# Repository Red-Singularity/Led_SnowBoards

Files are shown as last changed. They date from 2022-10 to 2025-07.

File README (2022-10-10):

The goal of this repository is to share code between all members who have custom LED snowbnoards to expedite the process of getting to the slopes
with actually functioning snowboards

This will not only include the code used on the boards but also possible testbeds, images, and other related files
This will be compartmentalized between users as all boards are built differently and require different code
this will allow merges to go a lot smoother since ideally only the user who created the code commited here will be modifying it
This also allows other people to view and test other members code though

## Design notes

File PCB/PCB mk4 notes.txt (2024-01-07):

* silk screen for labeling not showing
* level shifter needs to be the TXS0104EDR
* power switch needs pull down resistor
* op amp needs 12v power. only on when power switch is hit
* make connectors different for led data lines
* make sure fuse blows when crowbar circuit is active
* change diodes / thyristor circuit to actually work
* ground clamp test point (looping test point)
* bat test point messed up
* make components assemblable by jlcpcb
* better pin 1 markings
* bottom pad on mpu6050 doesnt exist
* add 10k pull up resistors to encoder data pins

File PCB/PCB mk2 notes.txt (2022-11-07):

keep dual xt-60
move connectors

have single xt-60 power output
use jst for signal output/input

less wide pcb

appropriately sized mosfets

fuse stupid size. keep soldered in

add rotary encoder / potentiometer

add i2c line 

fix foot print for gps

gyro fix footprint

mpu fix footprint

add current shunt if it doesnt affect size

make led dimmer, amount of status leds is good at 2

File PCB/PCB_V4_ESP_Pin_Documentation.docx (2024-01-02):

Left (EN button) Side Pins:

1. RESET
  a. GPIO: N/A
  b. Purpose: Resets the ESP32 and GPS module
  c. Connections:
    i. Reset test point
    ii. Reset pin (pin 8) of GPS module (NEO-M8M)
  d. Libraries: N/A
2. CELL1
  a. GPIO: 36
  b. Purpose: Analog input for cell 1 battery voltage from op-amp circuit
  c. Connections:
    i. CELL1 test point
    ii. CELL1 pin (pin 1) of op-amp (LM124DR)
  d. Libraries: N/A
3. CELL2
  a. GPIO: 39
  b. Purpose: Analog input for cell 2 battery voltage from op-amp circuit
  c. Connections:
    i. CELL2 test point
    ii. CELL2 pin (pin 7) of op-amp (LM124DR)
  d. Libraries: N/A
4. CELL3
  a. GPIO: 34
  b. Purpose: Analog input for cell 3 battery voltage from op-amp circuit
  c. Connections:
    i. CELL3 test point
    ii. CELL3 pin (pin 8) of op-amp (LM124DR)
  d. Libraries: N/A
5. SENSOR
  a. GPIO: 35
  b. Purpose: Analog input for 3-pin sensor (i.e. potentiometer or pressure-variable resistor)
  c. Connections:
    i. SENSOR test point
    ii. SENSOR pin (pin 1) of J8 connector (JST-XA type)
  d. Libraries: N/A
6. GATE_SIGNAL
  a. GPIO: 32
  b. Purpose: Digital output to control 12V power supply to the LEDs
  c. Connections:
    i. GATE_SIGNAL test point
    ii. Gate pin (pin 2) of Q1 MOSFET through R16
    iii. Gate pin (pin 2) of Q2 MOSFET through R17
    iv. GATE_SIGNAL pin (pin 8) of level shifter (TXS0104ED)
  d. Libraries: N/A
7. SW
  a. GPIO: 33
  b. Purpose: Digital input for the button switch on rotary encoder
    i. Note: We assume a normally HIGH switch (3.3V through R18). For a normally LOW switch, remove R18
  c. Connections:
    i. SW test point
    ii. SW pin (pin 3) of J9 connector (JST-XA type) for 5-pin rotary encoder
  d. Libraries: N/A
8. DT
  a. GPIO: 25
  b. Purpose: Digital input for circuit “A” of biphase rotary encoder
  c. Connections:
    i. DT test point
    ii. DT pin (pin 2) of J9 connector (JST-XA type) for 5-pin rotary encoder
  d. Libraries: <Encoder.h>
9. CLK
  a. GPIO: 26
  b. Purpose: Digital input for circuit “B” of biphase rotary encoder
  c. Connections:
    i. CLK test point
    ii. CLK pin (pin 1) of J9 connector (JST-XA type) for 5-pin rotary encoder
  d. Libraries: <Encoder.h>
10. SD_SW
  a. GPIO: 27
  b. Purpose: Digital input for detecting an SD card in the card socket
  c. Connections:
    i. SD_SW test point
    ii. SD_SW pin (pin 10) of micro-SD card socket (DM3AT-SF-PEJM5)
  d. Libraries: N/A
11. DATA_3
  a. GPIO: 14
  b. Purpose: Digital output for LED data on the 3rd data wire
  c. Connections:
    i. DATA_3 test point
    ii. DATA_3 pin (pin 4) of the level shifter (TXS0104ED)
      1. Signal output from the level shifter (pin 11) at 5V to pin 3 of J7 connector (JST-XA type)
  d. Libraries: <Adafruit_NeoPixel.h>
12. DATA_1
  a. GPIO: 12
  b. Purpose: Digital output for LED data on the 1st data wire
  c. Connections:
    i. DATA_1 test point
    ii. DATA_1 pin (pin 2) of the level shifter (TXS0104ED)
      1. Signal output from the level shifter (pin 13) at 5V to pin 1 of J7 connector (JST-XA type)
  d. Libraries: <Adafruit_NeoPixel.h>
13. DATA_2
  a. GPIO: 13
  b. Purpose: Digital output for LED data on the 2nd data wire
  c. Connections:
    i. DATA_2 test point
    ii. DATA_2 pin (pin 3) of the level shifter (TXS0104ED)
      1. Signal output from the level shifter (pin 12) at 5V to pin 2 of J7 connector (JST-XA type)
  d. Libraries: <Adafruit_NeoPixel.h>
14. GND
  a. GPIO: N/A
  b. Purpose: Ground pin of ESP32
  c. Connections: GND of PCB
  d. Libraries: N/A
15. x
  a. GPIO: N/A
  b. Purpose: VIN pin of ESP32 (not used here, as we supply 3.3V directly)
  c. Connections: N/A
  d. Libraries: N/A

Right (BOOT button) Side Pins:

16. MOSI
  a. GPIO: 23
  b. Purpose: VSPI serial output (from ESP32 to RAM and SD card)
  c. Connections:
    i. MOSI pin (pin 5) of RAM (Adafruit 4677)
    ii. MOSI test point
    iii. MOSI pin (pin 3) of micro-SD card socket (DM3AT-SF-PEJM5)
  d. Libraries:
    i. RAM: Needed
    ii. SD card: Needed
17. SCL
  a. GPIO: 22
  b. Purpose: I²C serial clock
  c. Connections:
    i. SCL pin (pin 5) of power monitor (INA220BIDGSR)
    ii. SCL test point
    iii. SCL pin (pin 23) of IMU (MPU-6050)
  d. Libraries:
    i. Power monitor: Needed
    ii. IMU: Needed
18. x
  a. GPIO: 1
  b. Purpose: not used, UART 0 TX
  c. Connections: N/A
  d. Libraries: N/A
19. x
  a. GPIO: 3
  b. Purpose: not used, UART 0 RX
  c. Connections: N/A
  d. Libraries: N/A
20. SDA
  a. GPIO: 21
  b. Purpose: I²C serial data line
  c. Connections:
    i. SDA pin (pin 4) of power monitor (INA220BIDGSR)
    ii. SDA test point
    iii. SDA pin (pin 24) of IMU (MPU-6050)
  d. Libraries:
    i. Power monitor: Needed
    ii. IMU: Needed
21. MISO
  a. GPIO: 19
  b. Purpose: VSPI serial input (from RAM and SD card to ESP32)
  c. Connections:
    i. MISO pin (pin 2) of RAM (Adafruit 4677)
    ii. MISO test point
    iii. MISO pin (pin 7) of micro-SD card socket (DM3AT-SF-PEJM5)
  d. Libraries:
    i. RAM: Needed
    ii. SD card: Needed
22. SCLK
  a. GPIO: 18
  b. Purpose: VSPI serial clock for RAM and SD card
  c. Connections:
    i. SCLK pin (pin 6) of RAM (Adafruit 4677)
    ii. SCLK test point
    iii. SCLK pin (pin 5) of micro-SD card socket (DM3AT-SF-PEJM5)
  d. Libraries:
    i. RAM: Needed
    ii. SD card: Needed
23. CS_SD
  a. GPIO: 5
  b. Purpose: SD card chip selection for VSPI serial communication
  c. Connections:
    i. CS_SD test point
    ii. CS_SD pin (pin 2) of micro-SD card socket (DM3AT-SF-PEJM5)
  d. Libraries: Needed
24. TX
  a. GPIO: 17
  b. Purpose: UART output (from ESP32 to GPS)
  c. Connections:
    i. TX test point
    ii. TX pin (pin 21) of GPS module (NEO-M8M-0)
  d. Libraries: <TinyGPS++.h> & <SoftwareSerial.h>
25. RX
  a. GPIO: 16
  b. Purpose: UART input (from GPS to ESP32)
  c. Connections:
    i. RX test point
    ii. RX pin (pin 20) of GPS module (NEO-M8M-0)
  d. Libraries: <TinyGPS++.h> & <SoftwareSerial.h>
26. INT
  a. GPIO: 4
  b. Purpose: Digital interrupt input (from IMU to ESP32)
    i. The MPU-6050 can be configured to give an interrupt signal for:
      1. Clock generator switching oscillator frequency
      2. New data available
      3. Accelerometer events
      4. Secondary I²C bus communication failure
  c. Connections:
    i. INT test point
    ii. INT pin (pin 12) of IMU (MPU-6050)
  d. Libraries: N/A
27. CS_RAM
  a. GPIO: 2
  b. Purpose: RAM chip selection for VSPI serial communication
  c. Connections:
    i. CS_RAM test point
    ii. CS_RAM pin (pin 1) of RAM (Adafruit 4677)
  d. Libraries: Needed
28. x
  a. GPIO: 15
  b. Purpose: Not used
  c. Connections: N/A
  d. Libraries: N/A
29. GND
  a. GPIO: N/A
  b. Purpose: Ground pin of ESP32
  c. Connections: GND of PCB
  d. Libraries: N/A
30. +3V3
  a. GPIO: N/A
  b. Purpose: 3.3V input of ESP32
  c. Connections: 3.3V rail of PCB
  d. Libraries: N/A

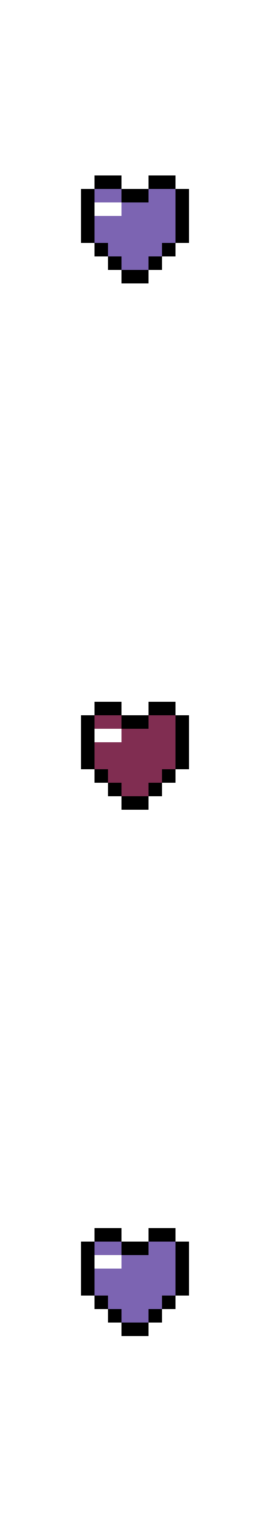
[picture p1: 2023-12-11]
_Dustin/media/The_Heart_of_Neon_board.gif

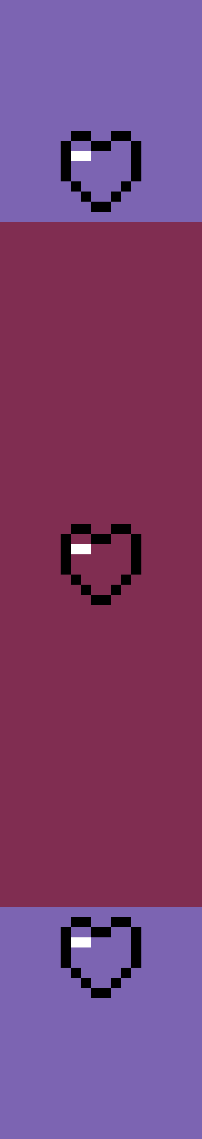
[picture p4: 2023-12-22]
_Dustin/media/The_Heart_of_Neon_board_background.gif

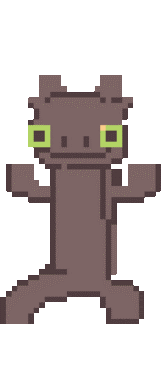
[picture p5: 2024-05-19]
_Dustin/media/toothless.gif

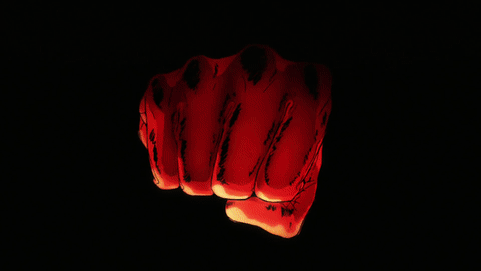
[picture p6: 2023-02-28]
_Dustin/media/onepunch.gif

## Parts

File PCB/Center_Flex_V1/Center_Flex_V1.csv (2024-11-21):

# | Reference | Qty | Value | Footprint | DNP
1 | FID1, FID2, FID3, FID4, FID5, FID6, FID7, FID8, FID9 | 9 | Fiducial | Fiducial:Fiducial_1.5mm_Mask3mm
2 | H1, H2, H3, H4, H5, H6, H7, H8 | 8 | MountingHole | Dustins_Footprints:4mm Solder Pad
3 | J1, J5, J9, J11, J15, J19, J24, J28, J34, J38, J117, J119 | 12 | Conn_01x02_Pin | Dustins_Footprints:Snowboard_Flex_Solder_Pad
4 | J2, J6, J10, J12, J16, J20, J23, J27, J33, J37, J118, J120 | 12 | Conn_01x02_Socket | Dustins_Footprints:Snowboard_Flex_Solder_pad_short
5 | J3, J7, J13, J17, J22, J26, J30, J32, J36, J40, J114, J116 | 12 | Conn_01x02_Socket | Dustins_Footprints:Snowboard_Flex_Solder_Pad
6 | J4, J8, J14, J18, J21, J25, J29, J31, J35, J39, J113, J115 | 12 | Conn_01x02_Pin | Dustins_Footprints:Snowboard_Flex_Solder_pad_short
7 | J41, J43, J44, J46 | 4 | Conn_01x01_Pin | Dustins_Footprints:5mm THT Circular
8 | J42, J45 | 2 | Conn_01x02_Socket | Dustins_Footprints:SnowBoard Flex Pass Through Pads Short
9 | J47, J50, J52, J54, J56, J58, J60, J62, J64, J66, J68, J70, J72, J74, J76, J78, J80, J81 | 18 | Conn_01x01_Socket | Dustins_Footprints:5mm THT Circular
10 | J48, J49, J51, J53, J55, J57, J59, J61, J63, J65, J67, J69, J71, J73, J75, J77, J79, J82 | 18 | Conn_01x01_Socket | Dustins_Footprints:5mm THT Square
11 | J83, J84, J85, J86, J87, J88, J89, J90, J98, J99, J100, J101, J102, J103, J104 | 15 | Conn_01x01_Pin | Dustins_Footprints:SnowBoard Power Pads
12 | J91, J92, J93, J94, J95, J96, J97, J105, J106, J107, J108, J109, J110, J111, J112 | 15 | Conn_01x01_Pin | Dustins_Footprints:SnowBoard Power Pads Short
13 | U1, U2, U3, U4, U5, U6, U7, U8, U9, U10, U11, U12, U13, U14, U15, U16, U17, U18, U19, U20, U21, U22, U23, U24, U25, U26, U27, U28, U29, U30, U31, U32, U33, U34, U35, U36, U37, U38, U39, U40, U41, U42, U43, U44, U45, U46, U47, U48, U49, U50, U51, U52, U53, U54, U55, U56, U57, U58, U59, U60, U61, U62, U63, U64, U65, U66, U67, U68, U69, U70, U71, U72, U73, U74, U75, U76, U77, U78, U79, U80, U81, U82, U83, U84, U85, U86, U87, U88, U89, U90, U91, U92, U93, U94, U95, U96, U97, U98, U99, U100, U101, U102, U103, U104, U105, U106, U107, U108, U109, U110, U111, U112, U113, U114, U115, U116, U117, U118, U119, U120, U121, U122, U123, U124, U125, U126, U127, U128, U129, U130, U131, U132, U133, U134, U135, U136, U137, U138, U139, U140, U141, U142, U143, U144, U145, U146, U147, U148, U149, U150, U151, U152, U153, U154, U155, U156, U157, U158, U159, U160, U161, U162, U163, U164, U165, U166, U167, U168, U169, U170, U171, U172, U173, U174, U175, U176, U177, U178, U179, U180, U181, U182, U183, U184, U185, U186, U187, U188, U189, U190, U191, U192, U193, U194, U195, U196, U197, U198, U199, U200, U201, U202, U203, U204, U205, U206, U207, U208, U209, U210, U211, U212, U213, U214, U215, U216, U217, U218, U219, U220, U221, U222, U223, U224, U225, U226, U227, U228, U229, U230, U231, U232, U233, U234, U235, U236, U237, U238, U239, U240, U241, U242, U243, U244, U245, U246, U247, U248, U249, U250, U251, U252, U253, U254, U255, U256, U257, U258, U259, U260, U261, U262, U263, U264, U265, U266, U267, U268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 | 840 | ~ | Dustins_Footprints:WS2816-2121

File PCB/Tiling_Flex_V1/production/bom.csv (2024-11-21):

Designator | Footprint | Quantity | Value | LCSC Part #
FID1, FID2, FID3, FID4, FID5, FID6, FID7, FID8, FID9 | Fiducial_1.5mm_Mask3mm | 9 | Fiducial
J1, J10, J11, J12, J13, J14, J15, J2, J3, J4, J5, J6, J7, J8, J9 | SnowBoard Power Pads | 15 | Conn_01x01_Pin
J100, J101, J102, J103, J104, J105, J106, J107, J108, J109, J110, J111, J112, J113, J114, J115, J116, J117, J118, J119, J120, J121, J122, J123, J124, J125, J126, J127, J128, J129, J130, J131, J132, J133, J134, J135, J136, J137, J138, J139, J140, J141, J142, J143, J144, J145, J146, J147, J148, J149, J150, J151, J152, J153, J154, J155, J156, J157, J158, J159, J160, J161, J162, J211, J212, J213, J214, J215, J216, J217, J218, J219, J220, J221, J222, J223, J224, J225, J226, J227, J228, J229, J230, J231, J232, J233, J234, J235, J236, J237, J238, J239, J240, J241, J242, J243, J244, J245, J246, J247, J248, J249, J250, J251, J252, J253, J254, J255, J256, J257, J258, J259, J260, J261, J262, J263, J264, J265, J266, J267, J268, J269, J270, J271, J272, J273, J274, J47, J48, J75, J76, J87, J88, J89, J90, J91, J92, J93, J94, J95, J96, J97, J98, J99 | Test Pad | 144 | Conn_01x01_Pin
J16, J17, J18, J19, J20, J21, J22, J23, J24, J25, J26, J27, J28, J29, J30 | SnowBoard Power Pads Short | 15 | Conn_01x01_Pin
J31, J37, J41, J45, J52, J56, J59, J65, J69, J73, J80, J84 | Snowboard_Flex_Solder_pad_short | 12 | Conn_01x02_Pin
J32, J38, J42, J46, J51, J55, J60, J66, J70, J74, J79, J83 | Snowboard_Flex_Solder_Pad | 12 | Conn_01x02_Socket
J33, J61 | SnowBoard Flex Pass Through Pads | 2 | Conn_01x02_Socket
J34, J62 | SnowBoard Flex Pass Through Pads Short | 2 | Conn_01x02_Pin
J35, J39, J43, J50, J54, J58, J63, J67, J71, J78, J82, J86 | Snowboard_Flex_Solder_pad_short | 12 | Conn_01x02_Socket
J36, J40, J44, J49, J53, J57, J64, J68, J72, J77, J81, J85 | Snowboard_Flex_Solder_Pad | 12 | Conn_01x02_Pin
JP1, JP10, JP11, JP12, JP13, JP14, JP15, JP16, JP17, JP18, JP19, JP2, JP20, JP21, JP22, JP23, JP24, JP25, JP26, JP27, JP28, JP29, JP3, JP30, JP31, JP32, JP33, JP34, JP35, JP36, JP37, JP38, JP39, JP4, JP40, JP41, JP42, JP43, JP44, JP5, JP6, JP7, JP8, JP9 | SolderJumper-2_P1.3mm_Open_RoundedPad1.0x1.5mm | 44 | SolderJumper_2_Open
U1, U10, U100, U106, U107, U108, U109, U11, U110, U111, U112, U113, U114, U115, U116, U117, U118, U119, U12, U120, U121, U122, U123, U124, U125, U126, U127, U128, U129, U13, U130, U14, U15, U16, U17, U18, U19, U2, U20, U21, U22, U23, U24, U25, U26, U27, U28, U29, U3, U30, U31, U32, U33, U34, U35, U4, U41, U42, U43, U44, U45, U46, U47, U48, U49, U5, U50, U51, U52, U53, U54, U55, U56, U57, U58, U59, U6, U60, U61, U62, U63, U64, U65, U66, U67, U68, U69, U7, U70, U71, U72, U73, U74, U75, U76, U77, U78, U79, U8, U80, U81, U82, U83, U84, U85, U86, U87, U88, U89, U9, U90, U91, U92, U93, U94, U95, U96, U97, U98, U99 | WS2816-2121 | 120 | ~

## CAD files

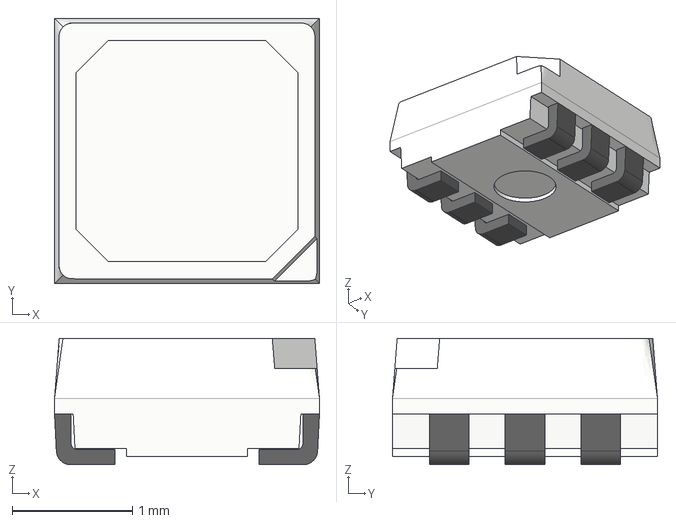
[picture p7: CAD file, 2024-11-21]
PCB/WS2816C-2121.step
2.20 x 2.20 x 1.05 mm

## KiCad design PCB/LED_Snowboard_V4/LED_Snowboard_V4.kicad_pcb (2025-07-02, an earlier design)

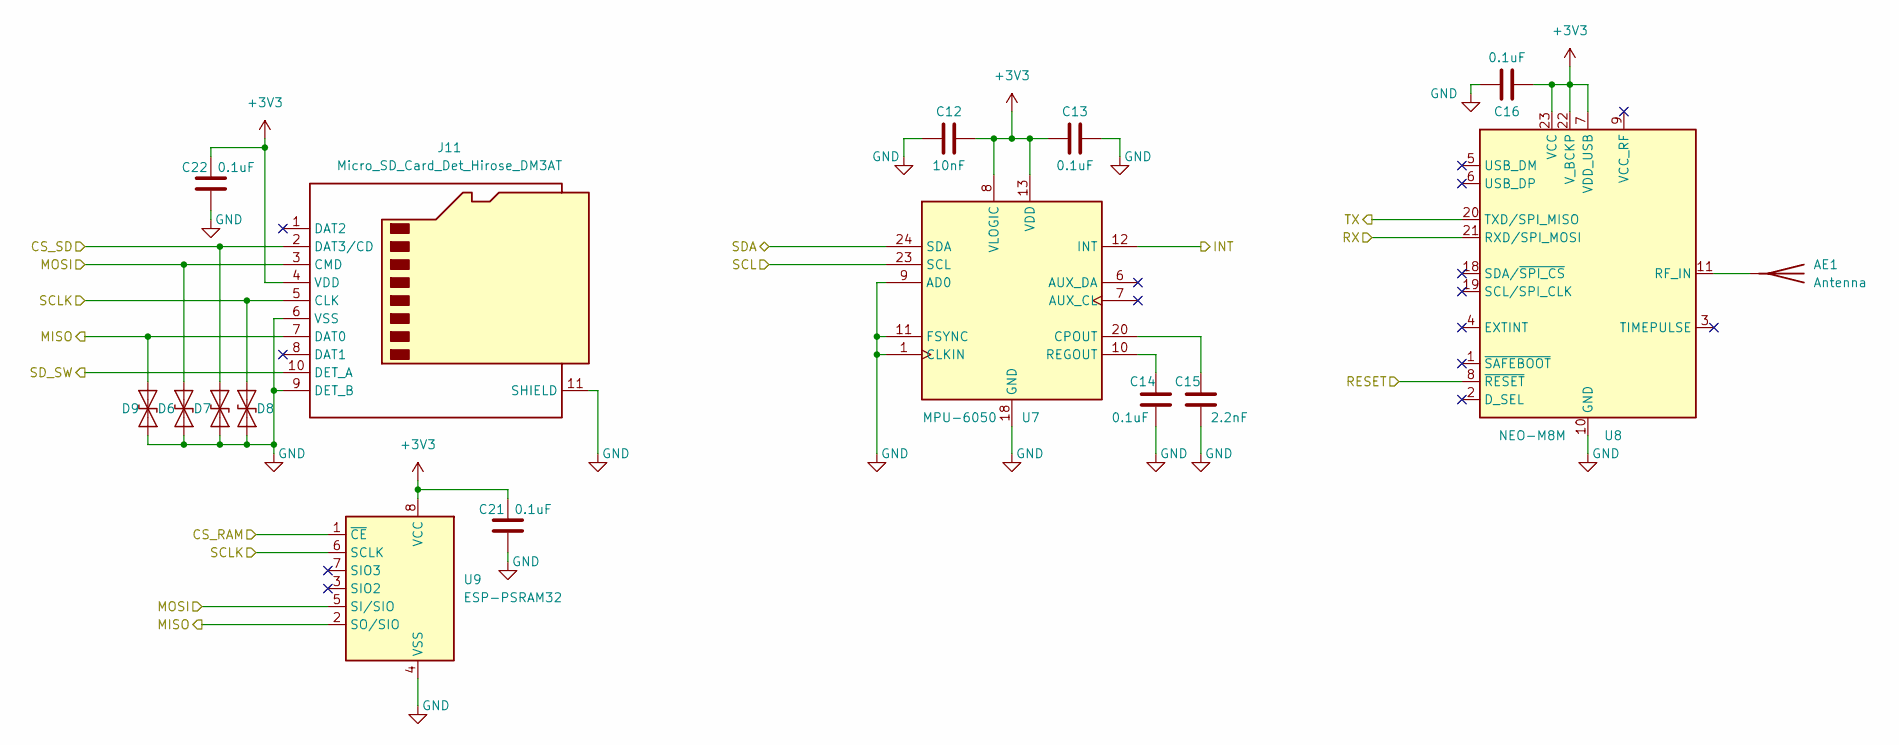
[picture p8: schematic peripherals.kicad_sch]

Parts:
AE1: Antenna; U.FL_Hirose_U.FL-R-SMT-1_Vertical
C12: 10nF; C_0603_1608Metric_Pad1.08x0.95mm_HandSolder
C13, C14, C16, C21, C22: 0.1uF; C_0603_1608Metric_Pad1.08x0.95mm_HandSolder
C15: 2.2nF; C_0603_1608Metric_Pad1.08x0.95mm_HandSolder
D6, D7, D8, D9: SD05_SOD323; D_SOD-323
J11: Micro_SD_Card_Det_Hirose_DM3AT; microSD_HC_Hirose_DM3AT-SF-PEJM5
U7: MPU-6050; InvenSense_QFN-24_4x4mm_P0.5mm
U8: NEO-M8M; ublox_NEO
U9: ESP-PSRAM32; SOIC-8_3.9x4.9mm_P1.27mm

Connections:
+3V3: C12.2, C13.1, C16.1, C21.2, C22.2, J11.4 (VDD), U7.8 (VLOGIC), U7.13 (VDD), U8.7 (VDD_USB), U8.22 (V_BCKP), U8.23 (VCC), U9.8 (VCC); also elsewhere on the board
/IO and Power/SCL: U7.23 (SCL); also elsewhere on the board
/IO and Power/SDA: U7.24 (SDA); also elsewhere on the board
/esp32/CS_RAM: U9.1 (~CE); also elsewhere on the board
/esp32/CS_SD: D7.2 (A2), J11.2 (DAT3/CD); also elsewhere on the board
/esp32/INT: U7.12 (INT); also elsewhere on the board
/esp32/MISO: D9.2 (A2), J11.7 (DAT0), U9.2 (SO/SIO); also elsewhere on the board
/esp32/MOSI: D6.2 (A2), J11.3 (CMD), U9.5 (SI/SIO); also elsewhere on the board
/esp32/RESET: U8.8 (~RESET); also elsewhere on the board
/esp32/RX: U8.20 (TXD/SPI_MISO); also elsewhere on the board
/esp32/SCLK: D8.2 (A2), J11.5 (CLK), U9.6 (SCLK); also elsewhere on the board
/esp32/SD_SW: J11.10 (DET_A); also elsewhere on the board
/esp32/TX: U8.21 (RXD/SPI_MOSI); also elsewhere on the board
GND: C12.1, C13.2, C14.1, C15.1, C16.2, C21.1, C22.1, D6.1 (A1), D7.1 (A1), D8.1 (A1), D9.1 (A1), J11.6 (VSS), J11.9 (DET_B), J11.11 (SHIELD), U7.1 (CLKIN), U7.9 (AD0), U7.11 (FSYNC), U7.18 (GND), U8.10 (GND), U8.12 (GND), U8.13 (GND), U8.24 (GND), U9.4 (VSS); also elsewhere on the board
unnamed: AE1.1 (A), U8.11 (RF_IN)
unnamed: C15.2, U7.20 (CPOUT)
unnamed: C14.2, U7.10 (REGOUT)

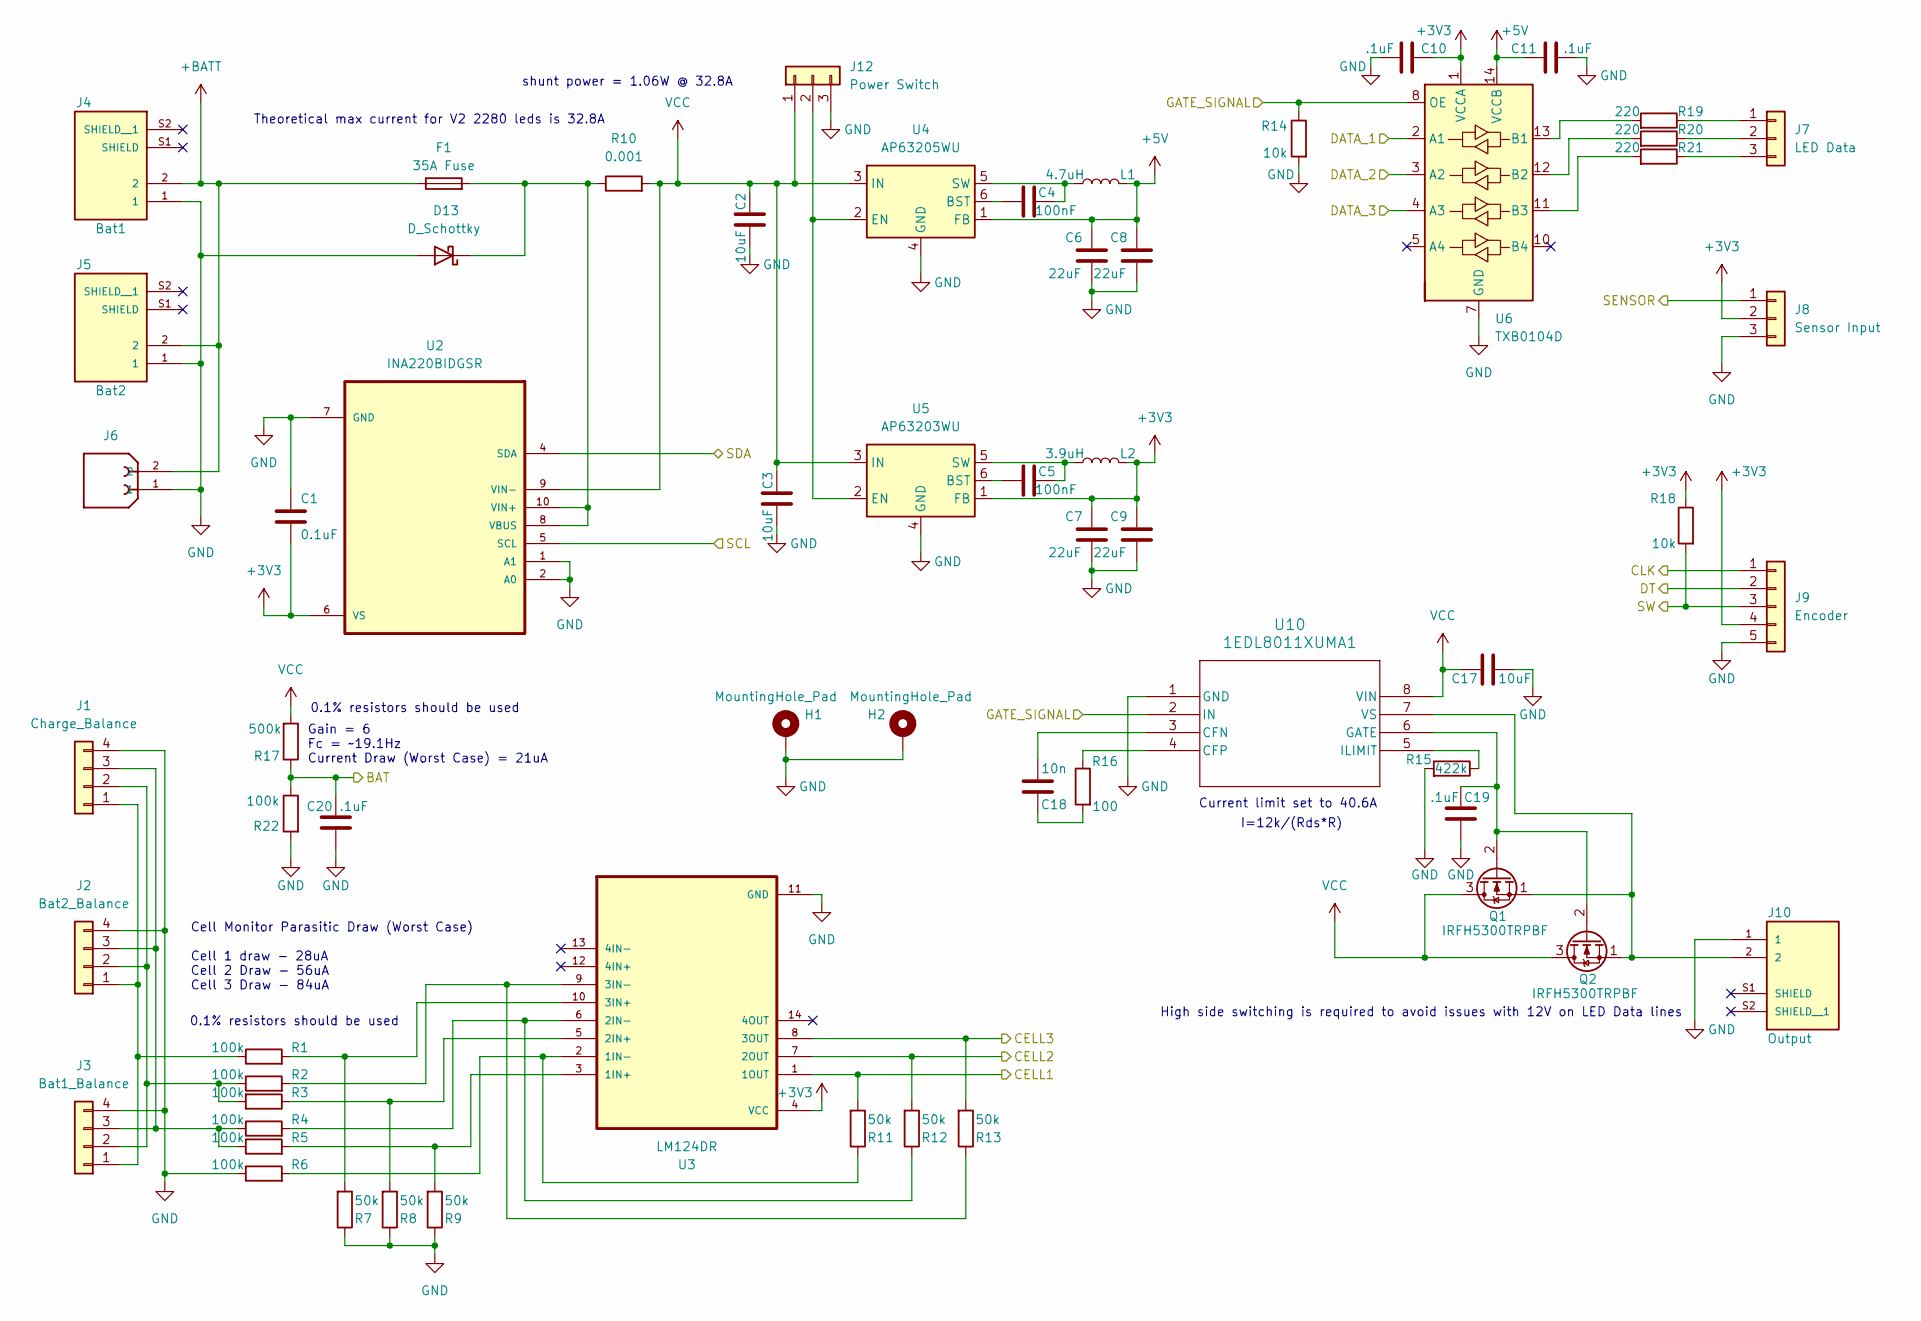
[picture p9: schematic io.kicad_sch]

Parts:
C1: 0.1uF; C_0603_1608Metric_Pad1.08x0.95mm_HandSolder
C2, C3, C17: 10uF; C_0603_1608Metric_Pad1.08x0.95mm_HandSolder
C4, C5: 100nF; C_0603_1608Metric_Pad1.08x0.95mm_HandSolder
C6, C7, C8, C9: 22uF; C_0603_1608Metric_Pad1.08x0.95mm_HandSolder
C10, C11, C19, C20: .1uF; C_0603_1608Metric_Pad1.08x0.95mm_HandSolder
C18: 10n; C_0603_1608Metric_Pad1.08x0.95mm_HandSolder
D13: D_Schottky; TO-263-3_TabPin2
F1: 35A Fuse; SF-3812F3500T-2
H1, H2: MountingHole_Pad; MountingHole_4.3mm_M4_Pad
J1: Charge_Balance; JST_XA_B04B-XASK-1_1x04_P2.50mm_Vertical
J2: Bat2_Balance; JST_XA_S04B-XASK-1N-BN_1x04_P2.50mm_Horizontal
J3: Bat1_Balance; JST_XA_S04B-XASK-1N-BN_1x04_P2.50mm_Horizontal
J4: Bat1; AMASS_XT60PW-M_1x02_P7.20mm_Horizontal; PARTREV V1.2
J5: Bat2; AMASS_XT60PW-M_1x02_P7.20mm_Horizontal; PARTREV V1.2
J6: AMASS_XT30U-M_1x02_P5.0mm_Vertical
J7: LED Data; JST_XA_B03B-XASK-1_1x03_P2.50mm_Vertical
J8: Sensor Input; JST_XA_B03B-XASK-1_1x03_P2.50mm_Vertical
J9: Encoder; JST_XA_B05B-XASK-1_1x05_P2.50mm_Vertical
J10: Output; AMASS_XT60PW-F_1x02_P7.20mm_Horizontal; PARTREV V1.2
J12: Power Switch; Molex_Nano-Fit_105309-xx03_1x03_P2.50mm_Vertical
L1: 4.7uH; IND_SRR4818A-150M
L2: 3.9uH; IND_SRR4818A-150M
Q1, Q2: IRFH5300TRPBF; PQFN-8-EP_6x5mm_P1.27mm_Generic
R1, R2, R3, R4, R5, R6, R22: 100k; R_0603_1608Metric_Pad0.98x0.95mm_HandSolder
R7, R8, R9, R11, R12, R13: 50k; R_0603_1608Metric_Pad0.98x0.95mm_HandSolder
R10: 0.001; RES_WSK12161L000FEA
R14, R18: 10k; R_0603_1608Metric_Pad0.98x0.95mm_HandSolder
R15: 422k; R_0603_1608Metric_Pad0.98x0.95mm_HandSolder
R16: 100; R_0603_1608Metric_Pad0.98x0.95mm_HandSolder
R17: 500k; R_0603_1608Metric_Pad0.98x0.95mm_HandSolder
R19, R20, R21: 220; R_0603_1608Metric_Pad0.98x0.95mm_HandSolder
U2: INA220BIDGSR; SOP50P490X110-10N
U3: LM124DR; SOIC127P600X175-14N
U4: AP63205WU; TSOT-23-6
U5: AP63203WU; TSOT-23-6
U6: TXB0104D; SOIC-14_3.9x8.7mm_P1.27mm
U10: 1EDL8011XUMA1; PG-DSO-8-92_INF

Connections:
+3V3: C1.2, C7.2, C9.2, C10.1, J8.2, J9.4, L2.2, R18.1, U2.6 (VS), U3.4 (VCC), U5.1 (FB), U6.1 (VCCA); also elsewhere on the board
+5V: C6.2, C8.2, C11.1, L1.2, U4.1 (FB), U6.14 (VCCB); also elsewhere on the board
+BATT: F1.1, J4.2, J5.2, J6.2; also elsewhere on the board
/IO and Power/BAT: C20.2, R17.1, R22.1; also elsewhere on the board
/IO and Power/CELL1: R11.2, U3.1 (1OUT); also elsewhere on the board
/IO and Power/CELL2: R12.2, U3.7 (2OUT); also elsewhere on the board
/IO and Power/CELL3: R13.2, U3.8 (3OUT); also elsewhere on the board
/IO and Power/CLK: J9.1; also elsewhere on the board
/IO and Power/DATA_1: U6.2 (A1); also elsewhere on the board
/IO and Power/DATA_2: U6.3 (A2); also elsewhere on the board
/IO and Power/DATA_3: U6.4 (A3); also elsewhere on the board
/IO and Power/DT: J9.2; also elsewhere on the board
/IO and Power/GATE_SIGNAL: R14.1, U6.8 (OE), U10.2 (IN); also elsewhere on the board
/IO and Power/SCL: U2.5 (SCL); also elsewhere on the board
/IO and Power/SDA: U2.4 (SDA); also elsewhere on the board
/IO and Power/SENSOR: J8.1; also elsewhere on the board
/IO and Power/SW: J9.3, R18.2; also elsewhere on the board
GND: C1.1, C2.1, C3.1, C6.1, C7.1, C8.1, C9.1, C10.2, C11.2, C17.1, C19.1, C20.1, D13.3 (A), H1.1, H2.1, J1.4, J2.4, J3.4, J4.1, J5.1, J6.1, J8.3, J9.5, J10.1, J12.3, R6.1, R7.1, R8.1, R9.1, R14.2, R15.2, R22.2, U2.1 (A1), U2.2 (A0), U2.7 (GND), U3.11 (GND), U4.4 (GND), U5.4 (GND), U6.7 (GND), U10.1 (GND); also elsewhere on the board
unnamed: C18.2, R16.2
unnamed: D13.2 (K), F1.2, R10.2, U2.8 (VBUS), U2.10 (VIN+)
unnamed: J1.1, J2.1, J3.1, R1.1
unnamed: J1.2, J2.2, J3.2, R2.1, R3.2
unnamed: J1.3, J2.3, J3.3, R4.1, R5.1
unnamed: J7.1, R19.1
unnamed: J7.2, R20.1
unnamed: J7.3, R21.1
unnamed: J12.2, U4.2 (EN), U5.2 (EN)
unnamed: C19.2, Q1.2 (G), Q2.2 (G), U10.6 (GATE)
unnamed: J10.2, Q1.1 (S), Q2.1 (S), U10.7 (VS)
unnamed: R5.2, R9.2, U3.3 (1IN+)
unnamed: R6.2, R11.1, U3.2 (1IN-)
unnamed: R3.1, R8.2, U3.5 (2IN+)
unnamed: R4.2, R12.1, U3.6 (2IN-)
unnamed: R1.2, R7.2, U3.10 (3IN+)
unnamed: R2.2, R13.1, U3.9 (3IN-)
unnamed: C4.1, U4.6 (BST)
unnamed: C4.2, L1.1, U4.5 (SW)
unnamed: C5.1, U5.6 (BST)
unnamed: C5.2, L2.1, U5.5 (SW)
unnamed: R19.2, U6.13 (B1)
unnamed: R20.2, U6.12 (B2)
unnamed: R21.2, U6.11 (B3)
unnamed: C18.1, U10.3 (CFN)
unnamed: R16.1, U10.4 (CFP)
unnamed: R15.1, U10.5 (ILIMIT)
VCC: C2.2, C3.2, C17.2, J12.1, Q1.3 (D), Q2.3 (D), R10.3, R17.2, U2.9 (VIN-), U4.3 (IN), U5.3 (IN), U10.8 (VIN); also elsewhere on the board

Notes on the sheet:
Current limit set to 40.6A
Gain = 6 Fc = ~19.1Hz Current Draw (Worst Case) = 21uA
Cell Monitor Parasitic Draw (Worst Case) Cell 1 draw - 28uA Cell 2 Draw - 56uA Cell 3 Draw - 84uA
I=12k/(Rds*R)
Theoretical max current for V2 2280 leds is 32.8A
High side switching is required to avoid issues with 12V on LED Data lines
0.1% resistors should be used
shunt power = 1.06W @ 32.8A

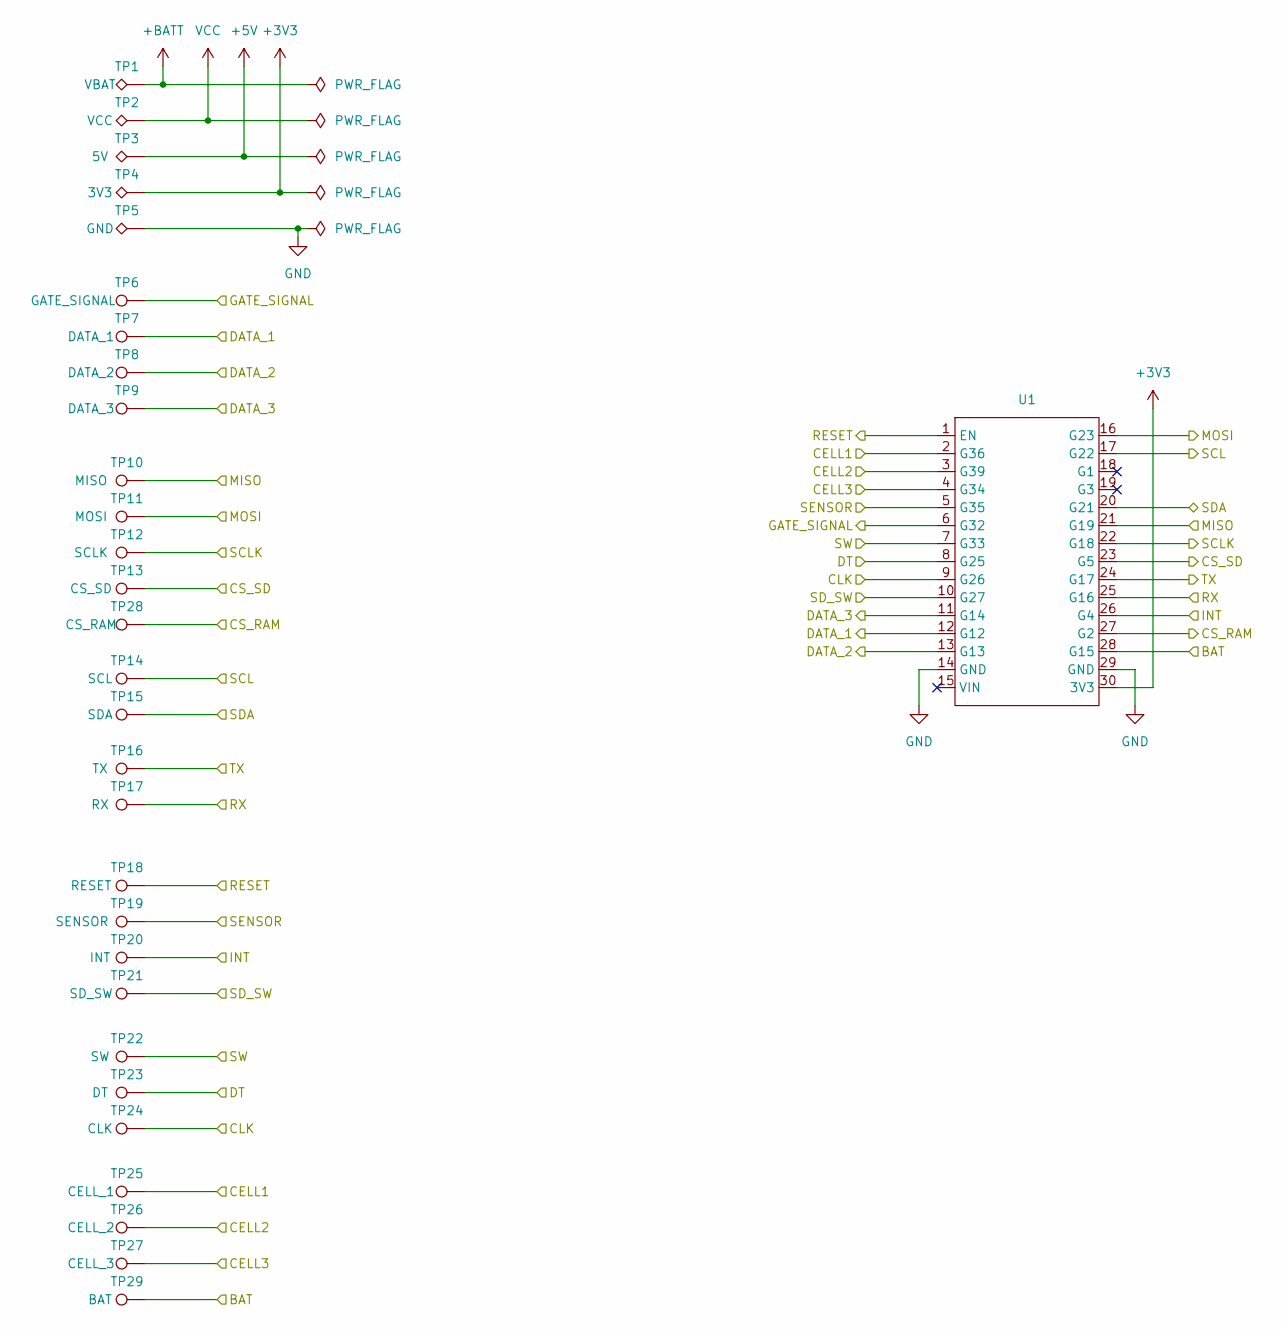
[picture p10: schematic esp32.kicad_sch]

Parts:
TP1: VBAT; TestPoint_Pad_3.0x3.0mm
TP2: VCC; TestPoint_Pad_3.0x3.0mm
TP3: 5V; TestPoint_Pad_3.0x3.0mm
TP4: 3V3; TestPoint_Pad_3.0x3.0mm
TP5: GND; TestPoint_Pad_3.0x3.0mm
TP6: GATE_SIGNAL; TestPoint_Pad_D1.5mm
TP7: DATA_1; TestPoint_Pad_D1.5mm
TP8: DATA_2; TestPoint_Pad_D1.5mm
TP9: DATA_3; TestPoint_Pad_D1.5mm
TP10: MISO; TestPoint_Pad_D1.5mm
TP11: MOSI; TestPoint_Pad_D1.5mm
TP12: SCLK; TestPoint_Pad_D1.5mm
TP13: CS_SD; TestPoint_Pad_D1.5mm
TP14: SCL; TestPoint_Pad_D1.5mm
TP15: SDA; TestPoint_Pad_D1.5mm
TP16: TX; TestPoint_Pad_D1.5mm
TP17: RX; TestPoint_Pad_D1.5mm
TP18: RESET; TestPoint_Pad_D1.5mm
TP19: SENSOR; TestPoint_Pad_D1.5mm
TP20: INT; TestPoint_Pad_D1.5mm
TP21: SD_SW; TestPoint_Pad_D1.5mm
TP22: SW; TestPoint_Pad_D1.5mm
TP23: DT; TestPoint_Pad_D1.5mm
TP24: CLK; TestPoint_Pad_D1.5mm
TP25: CELL_1; TestPoint_Pad_D1.5mm
TP26: CELL_2; TestPoint_Pad_D1.5mm
TP27: CELL_3; TestPoint_Pad_D1.5mm
TP28: CS_RAM; TestPoint_Pad_D1.5mm
TP29: BAT; TestPoint_Pad_D1.5mm
U1: MODULE_ESP32_DEVKIT_V1

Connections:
+3V3: TP4.1, U1.30 (3V3); also elsewhere on the board
+5V: TP3.1; also elsewhere on the board
+BATT: TP1.1; also elsewhere on the board
/IO and Power/BAT: TP29.1, U1.28 (G15); also elsewhere on the board
/IO and Power/CELL1: TP25.1, U1.2 (G36); also elsewhere on the board
/IO and Power/CELL2: TP26.1, U1.3 (G39); also elsewhere on the board
/IO and Power/CELL3: TP27.1, U1.4 (G34); also elsewhere on the board
/IO and Power/CLK: TP24.1, U1.9 (G26); also elsewhere on the board
/IO and Power/DATA_1: TP7.1, U1.12 (G12); also elsewhere on the board
/IO and Power/DATA_2: TP8.1, U1.13 (G13); also elsewhere on the board
/IO and Power/DATA_3: TP9.1, U1.11 (G14); also elsewhere on the board
/IO and Power/DT: TP23.1, U1.8 (G25); also elsewhere on the board
/IO and Power/GATE_SIGNAL: TP6.1, U1.6 (G32); also elsewhere on the board
/IO and Power/SCL: TP14.1, U1.17 (G22); also elsewhere on the board
/IO and Power/SDA: TP15.1, U1.20 (G21); also elsewhere on the board
/IO and Power/SENSOR: TP19.1, U1.5 (G35); also elsewhere on the board
/IO and Power/SW: TP22.1, U1.7 (G33); also elsewhere on the board
/esp32/CS_RAM: TP28.1, U1.27 (G2); also elsewhere on the board
/esp32/CS_SD: TP13.1, U1.23 (G5); also elsewhere on the board
/esp32/INT: TP20.1, U1.26 (G4); also elsewhere on the board
/esp32/MISO: TP10.1, U1.21 (G19); also elsewhere on the board
/esp32/MOSI: TP11.1, U1.16 (G23); also elsewhere on the board
/esp32/RESET: TP18.1, U1.1 (EN); also elsewhere on the board
/esp32/RX: TP17.1, U1.25 (G16); also elsewhere on the board
/esp32/SCLK: TP12.1, U1.22 (G18); also elsewhere on the board
/esp32/SD_SW: TP21.1, U1.10 (G27); also elsewhere on the board
/esp32/TX: TP16.1, U1.24 (G17); also elsewhere on the board
GND: TP5.1, U1.14 (GND), U1.29 (GND); also elsewhere on the board
VCC: TP2.1; also elsewhere on the board

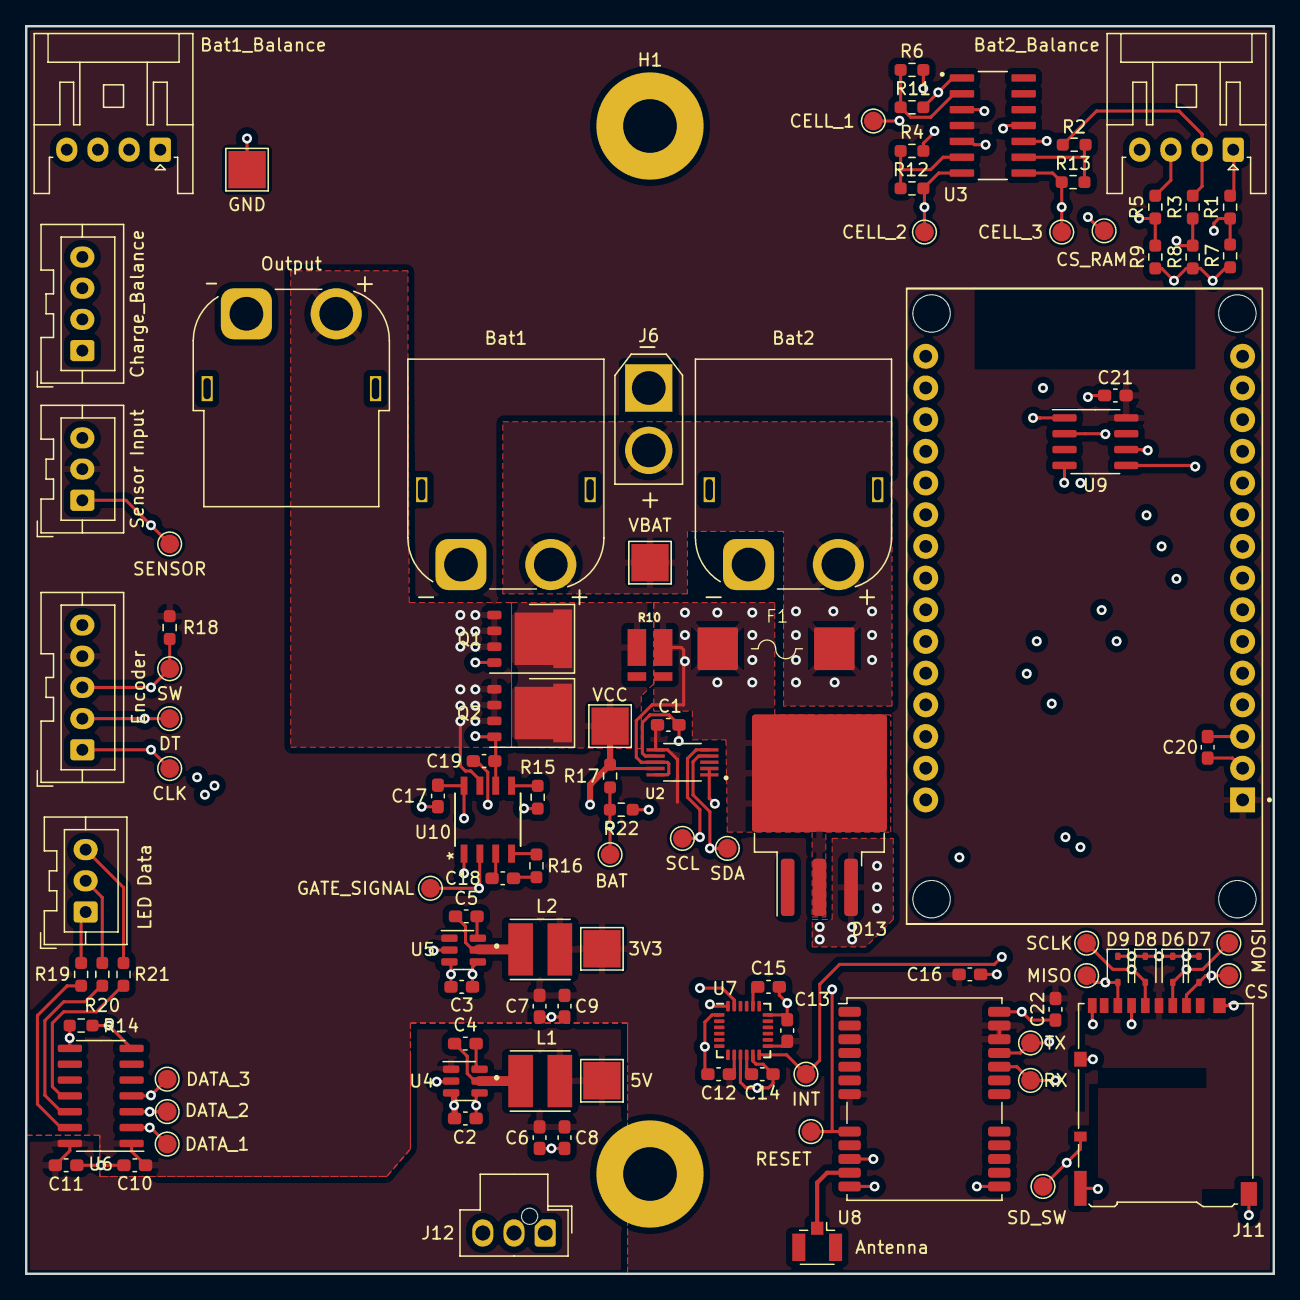
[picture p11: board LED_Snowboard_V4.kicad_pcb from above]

Board: 4 copper layers, 100.0 x 100.0 mm, 108 parts (0 on the bottom side), 59 nets.

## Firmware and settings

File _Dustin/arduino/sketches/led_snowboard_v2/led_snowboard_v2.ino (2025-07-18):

/*
Dustin Fisher

main code for the led matrix snowboard
This code controls my version of the led matrix snowboard. this includes an indivdually addressable
array fo 2090 leds on the base of the board which is actually split between two data pins on the esp32.
This board also has a set of leds on its top for miscellaious purposes which uses a single data pin.
This design utelizes a GPS for determining speed and a mpu-6050 for acceleromrter / gyroscope data. The
data for the bottom matrix will be stored on an sd card which is read frame by frame then displayed. the
rate at which it is displayed and various effects can be applied based on data collected from the mpu and GPS
*/

//#define FASTLED_INTERRUPT_RETRY_COUNT 1
//#define FASTLED_ALLOW_INTERRUPTS 0

#include "SdFat.h" // interfaces with sd card
#include "sdios.h" // sd card comms
#include "SPI.h" // handles SPI comms
#include "BluetoothSerial.h" // Bluetooth comms
#include <Wire.h> // i2c communication
#include <INA220.h> // for power monitor https://github.com/nathancheek/INA220
#include <FastLED.h> // main led control


//pin defines
#define CELL_1 36 // analog cell 1 data
#define CELL_2 39 // analog cell 2 data
#define CELL_3 34 // analog cell 3 data
#define SENSOR 35 // analog read sensor data
#define GATE_SIGNAL 32 //controls the mosfet for led strip power
#define SW 33 // Encoder switch
#define DT 25 // Encoder DT pin
#define CLK 26 // Encoder clock pin
#define SD_SW 27 // SD detect switch
#define DATA_3 14 // sets pin data is being sent from
#define DATA_1 12 // sets pin data is being sent from
#define DATA_2 13 // sets pin data is being sent from
#define MOSI 23 // MOSI SPI pin
#define SCL 22 // I2C clock pin
#define SDA 21 // I2C data pin
#define MISO 19 // MISO SPI pin
#define SCLK 18 // SPI clock pin
#define SD_CS_PIN 5 // SD card chip select
#define TX 17 // UART transmit pin
#define RX 16 // UART receive pin
#define INT 26 // mpu6050 interrupt
#define CS_RAM 2 // PSRAM chip select
#define BAT 15 // battery voltage voltage divider

//other defines
#define NUM_LEDS 2090 //2090 sets the amount of pixels being controlled
#define TOP_LEDS 60
#define MPU_addr 0x68 //i2c address of mpu
//setting for mpu degrees per second
#define dps2000 0x18
#define dps1000 0x10
#define dps500 0x08
#define dps250 0x00
//setting for mpu degrees per second
#define g16 0x18
#define g8 0x10
#define g4 0x08
#define g2 0x00

//spi speed
#define SPI_CLOCK SD_SCK_MHZ(25)

// Try to select the best SD card configuration.
#if HAS_SDIO_CLASS
#define SD_CONFIG SdioConfig(FIFO_SDIO)
#elif  ENABLE_DEDICATED_SPI
#define SD_CONFIG SdSpiConfig(SD_CS_PIN, DEDICATED_SPI, SPI_CLOCK)
#else  // HAS_SDIO_CLASS
#define SD_CONFIG SdSpiConfig(SD_CS_PIN, SHARED_SPI, SPI_CLOCK)
#endif  // HAS_SDIO_CLASS

//initialize sd card class as sd
SdFat SD;

//initialize File class as file
File file;

//initialize BluetoothSerial class as SerialBT
BluetoothSerial SerialBT;

//INA220 library initialization as ina220
INA220 ina220;

//initialize led strips
CRGB half1[NUM_LEDS/2];
CRGB half2[NUM_LEDS/2];
CRGB top[TOP_LEDS];

TaskHandle_t LEDs; // dedicated task and loop to handle LEd output and avoid bluetooth code interference

// Create a Serial output stream.
//ArduinoOutStream cout(Serial);

//Global variables
int frameData[NUM_LEDS]; // array of data for single frame
int cal = 50; // amount of loops to get gyro data for calibration
int offsetx, offsety, offsetz; // offset values for gyro
int counter = 0; // generic counter for testing
int frame_number = 0; // sets the frame being displayed for the current gif

const uint8_t NUM_INA = 1; // 1 INA device
const uint8_t MAX_CUR = 40; 
const uint16_t SHUNT_R = 1000; // 1 mOhm

uint8_t ina_addresses[NUM_INA] = {0x40}; // INA I2C addresses

bool bat_safe = 0; //flag for enabling or disabling low battery cutoff. 1 = safety enabled
bool rand_LED = 0; // flag for random sequence animation
bool freefall = 0; // flag for freefall detection
bool media1 = 0;
bool media2 = 0;
bool media3 = 0;
bool media4 = 0;
bool media5 = 0;

float ax, ay, az; // accelerometer data in Gs
float gx, gy, gz; // gyro data in degrees/second
float comp_x, comp_y = 0; // complimentary filter angles
float gyro_angle_x, gyro_angle_y, gyro_angle_z = 0; // angle calculated with gyro
float temp_c; // temperature sensor on mpu. in degrees c
float mpu_timer = 0; // timer to get data from gyro in mpu
float voltage, current, power; // ina chip values
float timer = 0; // generic timer
float minCell = 4.2; // minimum cell voltage reading

String accel_set = "16g"; // 2g, 4g, 8g, 16g
String gyro_set = "2000dps"; // 250dps, 500dps, 1000dps, 2000dps


void setup() {
  //setup serial output
  Serial.begin(115200);

  //set pin modes
  pinMode(DATA_1, OUTPUT); // set led data pins to output
  pinMode(DATA_2, OUTPUT); 
  pinMode(DATA_3, OUTPUT);
  pinMode(GATE_SIGNAL, OUTPUT); // turns on 12v to leds
  pinMode(BAT, INPUT);


  xTaskCreatePinnedToCore(
    LEDs_Code, /* Function to implement the task */
    "LEDs", /* Name of the task */
    10000,  /* Stack size in words */
    NULL,  /* Task input parameter */
    0,  /* Priority of the task */
    &LEDs,  /* Task handle. */
    0); /* Core where the task should run */

  //device setups
  //INA_setup(); //INA220 setup
  sd_setup(); //setup sd card
  bluetooth_setup(); //setup bluetooth
  //mpu_setup(); //setup mpu
  //setup GPS
  
  //setup led strips
  digitalWrite(GATE_SIGNAL, false);
  FastLED.addLeds<WS2812, DATA_1, BGR>(half1, NUM_LEDS);
  FastLED.addLeds<WS2812, DATA_2, BGR>(half2, NUM_LEDS);
  FastLED.addLeds<WS2812, DATA_3, BGR>(top, TOP_LEDS);
  FastLED.setCorrection(TypicalLEDStrip);
  //set brightness to 5%
  FastLED.setBrightness(5);
  FastLED.show();
  
}

void loop() {
  timer = millis();

  bluetooth_control(); // use data over bluetooth to control images
  //getInaValues(); //get board status (battery info, current measurements, etc)
  //getBatteryData(); // get all battery data
  //get MPU data
  //get GPS data
  //app();
  //get gps data
  FastLED.show();

  //Serial.println(millis()-timer);
}


void LEDs_Code( void * parameter) {
  for(;;) {
  }
}

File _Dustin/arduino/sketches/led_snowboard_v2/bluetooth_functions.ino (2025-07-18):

void bluetooth_setup(){
  //setup bluetooth connections
  SerialBT.begin("LED_Snowboard_V2"); //name given to esp32
  Serial.println("\n The device started, now you can pair it with bluetooth!");
}

void bluetooth_control(){
  // a set of if statements to read data from the terminal and control the board
  bool command = 0;
  char incomingChar;
  String message = "";

  while(SerialBT.available()){
    incomingChar = char(SerialBT.read()); // read what is in serial buffer
    Serial.print(incomingChar);
    if(incomingChar == '\n'|| incomingChar == '\0' || incomingChar == '\r'){ // see if terminating character appears
      command = 1; //allow command to be read by code
      break; // leave while loop
    }
    else{
      message += incomingChar; // add character to bluetooth command string
    }
  }

  if(command){
    command = 0;

    //turn board on
    if(message == "FF"){
      Serial.println("On");
      if ((bat_safe == 1) && (voltage < 9.5)){
        digitalWrite(GATE_SIGNAL, false);
        SerialBT.println("Error - Low Voltage");
      }
      else{
        digitalWrite(GATE_SIGNAL, true);
        SerialBT.println("On");
      }
    }

    //turn board off
    else if(message == "FE"){
      Serial.println("Off");
      digitalWrite(GATE_SIGNAL, false);
      SerialBT.println("Off");
    }

    //read battery values
    else if(message == "0B"){
      SerialBT.print("Battery Voltage: ");
      SerialBT.println(voltage);
      SerialBT.print("Min Cell Voltage: ");
      SerialBT.println(minCell);
      SerialBT.print("Total Current: ");
      SerialBT.println(current);
      SerialBT.print("Total Power: ");
      SerialBT.println(power);
    }

    //disable low battery cut off
     else if(message == "0D"){
      bat_safe = 0;
      SerialBT.println("Battery Safety Diabled");
    }

    //enable low battery cutoff ( is set to on by default)
     else if(message == "0C"){
      bat_safe = 1;
      SerialBT.println("Battery Safety Enabled");
    }

    //set color to white
    else if(message == "06"){
      SerialBT.println("Color - White");
      rand_LED = 0;
      media1 = 0;
      media2 = 0;
      media3 = 0;
      media4 = 0;
      media5 = 0;
      for(int i=0; i<(NUM_LEDS/2); i++){
        half1[i] = CRGB::White;
        half2[i+1] = CRGB::White;
      }
      for(int i=0; i<TOP_LEDS; i++){
      }
    }

    //set color to Green
    else if(message == "07"){
      //SerialBT.println("Color - Green");
      rand_LED = 0;
      media1 = 0;
      media2 = 0;
      media3 = 0;
      media4 = 0;
      media5 = 0;
      for(int i=0; i<(NUM_LEDS/2); i++){
        half1[i] = CRGB::Green;
        half2[i+1] = CRGB::Green;
      }
      for(int i=0; i<TOP_LEDS; i++){
      }
    }

    //set color to Red
    else if(message == "08"){
      SerialBT.println("Color - Red");
      rand_LED = 0;
      media1 = 0;
      media2 = 0;
      media3 = 0;
      media4 = 0;
      media5 = 0;
      for(int i=0; i<(NUM_LEDS/2); i++){
        half1[i] = CRGB::Red;
        half2[i+1] = CRGB::Red;
      }
      for(int i=0; i<TOP_LEDS; i++){
      }
    }

    //set color to Blue
    else if(message == "09"){
      SerialBT.println("Color - Blue");
      rand_LED = 0;
      media1 = 0;
      media2 = 0;
      media3 = 0;
      media4 = 0;
      media5 = 0;
      for(int i=0; i<(NUM_LEDS/2); i++){
        half1[i] = CRGB::Blue;
        half2[i+1] = CRGB::Blue;
      }
      for(int i=0; i<TOP_LEDS; i++){
      }
    }

    //set color to Random
    else if(message == "0A"){
      SerialBT.println("Color - Random");
      rand_LED = 1;
      media1 = 0;
      media2 = 0;
      media3 = 0;
      media4 = 0;
      media5 = 0;
    }

    //set brightness to 5%
    else if(message == "00"){
      SerialBT.println("Brightness - 5%");
      FastLED.setBrightness(5);
    }

    //set brightness to 10%
    else if(message == "01"){
      SerialBT.println("Brightness - 10%");
      FastLED.setBrightness(10);
    }

    //set brightness to 25%
    else if(message == "02"){
      SerialBT.println("Brightness - 25%");
      FastLED.setBrightness(25);
    }

    //set brightness to 50%
    else if(message == "03"){
      SerialBT.println("Brightness - 50%");
      FastLED.setBrightness(50);
    }

    //set brightness to 75%
    else if(message == "04"){
      SerialBT.println("Brightness - 75%");
      FastLED.setBrightness(75);
    }

    //set brightness to 100%
    else if(message == "05"){
      SerialBT.println("Brightness - 100%");
      FastLED.setBrightness(100);
    }

    //assign media 1 to board
    else if(message == "10"){
      SerialBT.println("media1");
      frame_number = 0;
      rand_LED = 0;
      media1 = 1;
      media2 = 0;
      media3 = 0;
      media4 = 0;
      media5 = 0;
    }

    //assign media 2 image to board
    else if(message == "11"){
      SerialBT.println("media2");
      frame_number = 0;
      rand_LED = 0;
      media1 = 0;
      media2 = 1;
      media3 = 0;
      media4 = 0;
      media5 = 0; 
    }

    //assign media 3 to the board
    else if(message == "12"){
      SerialBT.println("media3");
      frame_number = 0;
      rand_LED = 0;
      media1 = 0;
      media2 = 0;
      media3 = 1;
      media4 = 0;
      media5 = 0;
    }
    //assign media4 to the board
    else if(message == "13"){
      SerialBT.println("media4");
      frame_number = 0;
      rand_LED = 0;
      media1 = 0;
      media2 = 0;
      media3 = 0;
      media4 = 1;
      media5 = 0;
    }
    //assign media 5 board to the board
    else if(message == "14"){
      SerialBT.println("media5");
      frame_number = 0;
      rand_LED = 0;
      media1 = 0;
      media2 = 0;
      media3 = 0;
      media4 = 0;
      media5 = 1;
    }
  //debugging function
    else if(message == "list"){
      Serial.print("list");
    }
  
    else{}

    message = ""; // reset command string
  }

//-------------------------------------------------------------------------------

  if (rand_LED == 1){
    for(int i=0; i<(NUM_LEDS/2); i++){
      half1[i] = random(0, 0xFFFFFF);
      half2[i+1] = random(0, 0xFFFFFF);
    }
    for(int i=0; i<TOP_LEDS; i++){
    }
  }

  if (media1 == 1){
    assign_media1();
  }

  if (media2 == 1){
    assign_media2();
  }

  if (media3 == 1){
    assign_media3();
  }

  if (media4 == 1){
    assign_media4();
  }

  if (media5 == 1){
    assign_media5();
  }
}

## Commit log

2022-10-11 added pcb files
    added easy eda pcb files as zip
2022-10-16 Figured out how to transfer data from non standard array to image
    Using the addition of a couple new functions I was able to create generic functions that can write either the data needed or a 0 depending on how the snowboard is laid out. In order to test I need to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
2022-10-20 Fixed array size issue
    fixed issue with array sizes stemming from improper tracking of place in row where data is assigned. need to fix split section of board and create a fade pattern for testing
2022-10-22 Working Sim!
    supposedly fully working simulator. uses fading rgb values to confirm led strip direction and shape
2022-10-22 deleted useless comments and used nearest neighbor filter
2022-10-23 started image translator
    started python file that converts images into single dimensional array the board can read
2022-10-26 Almost have image translator working
    Just about finished the image translator. there is a weird pixel shifting error on the second side of the board. Its unclear if this is a fault of the simulator or the image translator
2022-10-28 added image_positioning function
    added image positioning function which centers image on the board. Also added capability to adjust background color in the simulator
2022-11-07 Started arduino test code
    started basic tests with arduino to read data from sd card
2022-11-13 Ability to read files to array
    started main snowboard code and determined how to read files to an array at variable speeds up to 50mhz on spi
2022-11-18 added mpu functions
    created functions to set parameters and get data from mpu6050. this includes all axis for gyro and accel, calibration function for gyro, and getting temperature readings
2023-01-27 Tremblant trip
    added basic bluetooth control for colors, rand function and brightness as well as battery low voltage cutoff
2023-01-31 nyan prep
    prepped arduino code to test nyan cat image. also re simulated nyan cat and made custom folder to hold data.
2023-01-31 successful nyan cat
    created a gif of nyan cat that is displayed properly on the board
2023-03-03 fixed small issues
    fixed small issues in arduino code and simulator.
    [led_snowboard_v2.ino, mpu_functions.ino, sd_functions.ino]
2023-04-28 added led snowboard v1
    added old sketches for v1 to repository
2023-10-19 Moved to Kicad
    created replica of pcb schematic in kicad and started work on app again
    [LED_Snowboard_V4.kicad_pcb, LED_Snowboard_V4.kicad_sch, esp32.kicad_sch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]
2023-10-19 Transfer PCB To Desktop
    [LED_Snowboard_V4.kicad_sch, esp32.kicad_sch, io.kicad_sch]
2023-10-21 Post Review
    Reviewed with Tim. need to add power line protections. settled on no battery heater for now
    [LED_Snowboard_V4.kicad_sch, esp32.kicad_sch, io.kicad_sch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]
2023-10-24 pcb transfer to laptop
    [LED_Snowboard_V4.kicad_sch, io.kicad_sch]
2023-11-30 routed all main lines and added power vias
    [LED_Snowboard_V4.kicad_pcb]
2023-11-30 main routing complete v4
    [LED_Snowboard_V4.kicad_pcb]
2023-12-04 Added all smd footprints
    just need to add jst connectors and change gps antennae
    [LED_Snowboard_V4.kicad_pcb]
2023-12-05 impedance matched antennae
    [LED_Snowboard_V4.kicad_pcb]
2023-12-05 finished v4 design before review
    [LED_Snowboard_V4.kicad_pcb]
2023-12-07 Added Ram
    Added Ram. need to finish DRC checks
    [LED_Snowboard_V4.kicad_pcb, LED_Snowboard_V4.kicad_sch, esp32.kicad_sch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]
2023-12-11 Finished PCB with all feedback
    [LED_Snowboard_V4-B_Cu.gbl, LED_Snowboard_V4-B_Mask.gbs, LED_Snowboard_V4-B_Paste.gbp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]
2023-12-22 Updated Arduino Code
    updated arduino code for use with V4 board and added some test scripts. also got the board to work with SD card
2024-01-04 Fixed frame read issues
    fixed issue where setting sd card read would freeze all commands. also added op amp readings.
    [battery_data.ino, bluetooth_functions.ino, led_snowboard_v2.ino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]
2024-01-07 arduino tweaks and pcb notes
2024-10-13 Center Flex Fixes
    fixed board outline to matrix misalignment issue and added extra pads for pass through from tiling board
    [150cm_Flex.kicad_pcb, 150cm_Flex.kicad_sch, Center_Flex_V1.kicad_sch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]
2024-11-21 Flex PCBs ordered
    All Flex PCBs are finalized and ordered
    [Center Flex V1 BOM.csv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]
2025-07-02 updated control pcb
    updated to add high side switching as well as added voltage divider and adjusted layout
    [150cm_Flex.kicad_sch, Center_Attatch.kicad_sch, ESP32.kicad_sch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]
2025-07-13 oredered board
    [LED_Snowboard_V4-B_Cu.gbl, LED_Snowboard_V4-B_Mask.gbs, LED_Snowboard_V4-B_Paste.gbp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]
2025-07-17 confirmed working code before opensauce
    confirmed the image translator and simulator works before open sauce. also verified all arduino code works but could use debugging on V2 to fix glitching
    [battery_data.ino, bluetooth_functions.ino, led_snowboard_v2.ino]
